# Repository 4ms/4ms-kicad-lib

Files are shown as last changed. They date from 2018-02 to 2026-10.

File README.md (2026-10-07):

4ms-kicad-lib
-------------

Intro:
-----

4ms-kicad-lib is a collection of symbol and footprint libraries for KiCad 10.
These libraries were created by and for people working at [4ms
Company](https://4mscompany.com). We share them publicly in hopes they help
others design great circuits. Have fun.

There are also some legacy symbol libraries for KiCad 5.1.x in
`symbols-legacy`, but they will not be updated or maintained, and they aren't
included in the KiCad Plugin and Content Manager archive.

We tried to follow the KiCad Library Conventions, although we made breaks from
that where it made sense. We also tried to keep the look and feel of the
official KiCad symbols, to make using this library and the official KiCad
libraries seamless.

What's in here:
--------------
__Libraries (KiCad PCM archive):__

`symbols`: The symbol library (schematic symbols). As of May 2020, we have
switched to using a unique symbol for each physical component that might appear
on a BOM line.

`footprints`: The footprint library (pcb). Library names tend to follow the
standard of the official KiCad .pretty libraries, but with a "4ms_" prefix. One
interesting library is the `4ms_Faceplate.pretty`: these are intended to be
used with our faceplate generation scripts. Each component is a hole or slot
that's the correct size for a particular faceplate-mounted component. 

`3dmodels`: 3D models for the footprints, organized similar to how the official
KiCad 3dmodels are organized.

__Other stuff (not in KiCad PCM archive):__

`design-blocks`: These are design blocks that we re-use. We're still new to
this workflow, so it's not part of the PCM release until we figure out how to
best package these.

`symbols-legacy/kicad5-2021`: The legacy symbol library for KiCad 5.1.x. This
is a snapshot of the libraries at Nov 19, 2021. It will not be updated or
maintained.

`symbols-legacy/kicad5-2019`: An even older library using non-atomic symbols
(generic resistor, capacitor, etc). This was deprecated in May 2020. It is no
longer maintained or updated.

`footprints-legacy`: The legacy footprint library, not really of much use since
PCBs embed the footprints they used.

`packages3d`: Legacy random 3d models, please verify dimensions before relying
on the accuracy of these models.

`lib-table-files`: The library table files. People working on 4ms projects
should copy these into a project directory (See step 2B below).

`schematic-blocks`: KiCad schematic sheets of basic circuits we use over and
over. These building blocks are intended to be used as hierarchical sheets, or
just copy/pasted into your design. They are in KiCad 5 format at the moment but
can be used by KiCad 6 as well.

How to Install Symbol and Footprint Libraries:
----------

__Step 1) Download or install the 4ms libraries__

Download or clone the 4ms-kicad-lib git repo onto your local hard drive. Or use
KiCad's Plugin and Content Manager (PCM) to install this.

If downloading manually, save this repo folder in the same directory as all
your KiCad projects or wherever you want to keep you KiCad libraries.

If you use the KiCad PCM tool, the libraries will be installed in your
`KICAD6_3RD_PARTY` directory (on macOS it's
/Users/YourUserName/Documents/KiCad/6.0/3rdparty, for example).

__Step 2) Add the libraries to your library tables__

  * Select `Manage Symbol Libraries` (in the schematic editor) or `Manage
    Footprint Libraries` (in the pcb editor) in the Preferences menu.
  * Select the Global tab (if you want to access these libraries from *all*
    your projects), or select the Project tab (if you just want to use the
    libraries in the current project).
  * Click the tiny folder icon at the base of the list box, and then browse to
    the libraries you want to add. On MacOS you can Cmd-click to select
    multiple libraries at once.
  * Repeat for both the symbol libraries and the footprint libraries.
  * Libraries can be available but just hidden (disabled). To enable/disable a
    library, use the checkbox next to the libraries name.

__Alternative step 2) Setup the environment variables and copy lib tables__

If you want to add **all** the 4ms libraries to your project (which is what
anyone working at 4ms will always want to do), then just copy the two files in
lib-table-files/ to your project directory.

For this to work, you need to first create an environment variable called
`KICAD_4MS_LIBS` and set it to the path to this library folder. You only have
to do this part once, it applies globally to all projects. To do this:
    * Go to the KiCad project window and select `Configure Paths` in the
      `Preferences` menu. 
    * Add a new entry with the name `KICAD_4MS_LIBS`. Set the value to the full
      path of the 4ms-kicad-lib folder. Example: `KICAD_4MS_LIBS:
      /Users/YOURUSERNAME/WhateverFolder/MyKiCadProjects/4ms-kicad-lib`

More resources
----------

The symbol library works well with our BOM scripts (exporting files compatible
with JLCPCB, for example). We also have a series of scripts that generate a
Eurorack faceplate from a PCB, and more. These can be found in our script repo:
https://github.com/4ms/4ms-kicad-script

LICENSE
-------

These are in the public domain under the Unlicense.

TODO
----

  * Add better descriptions for each library

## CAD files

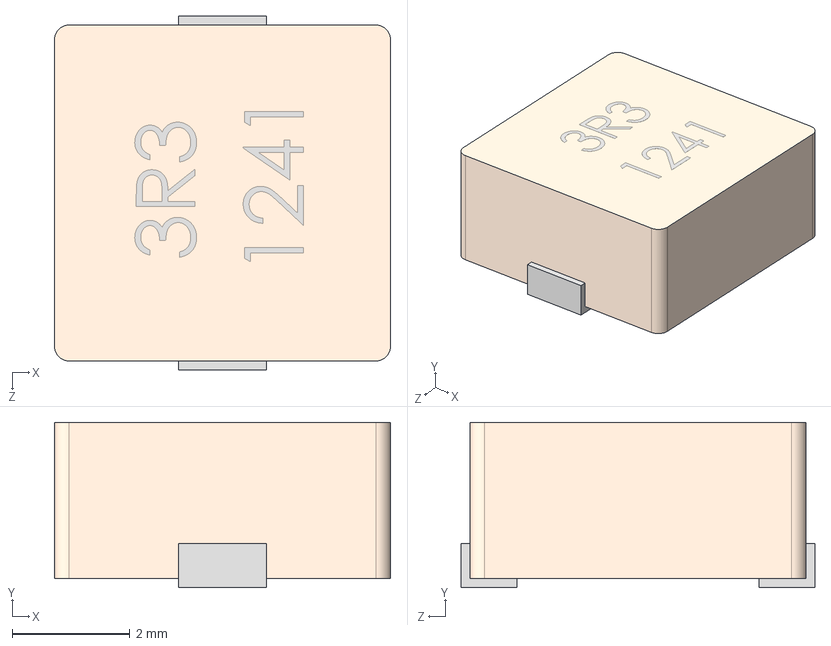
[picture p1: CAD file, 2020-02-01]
3dmodels/Inductors/SRP5030T.step
5.70 x 2.80 x 6.00 mm

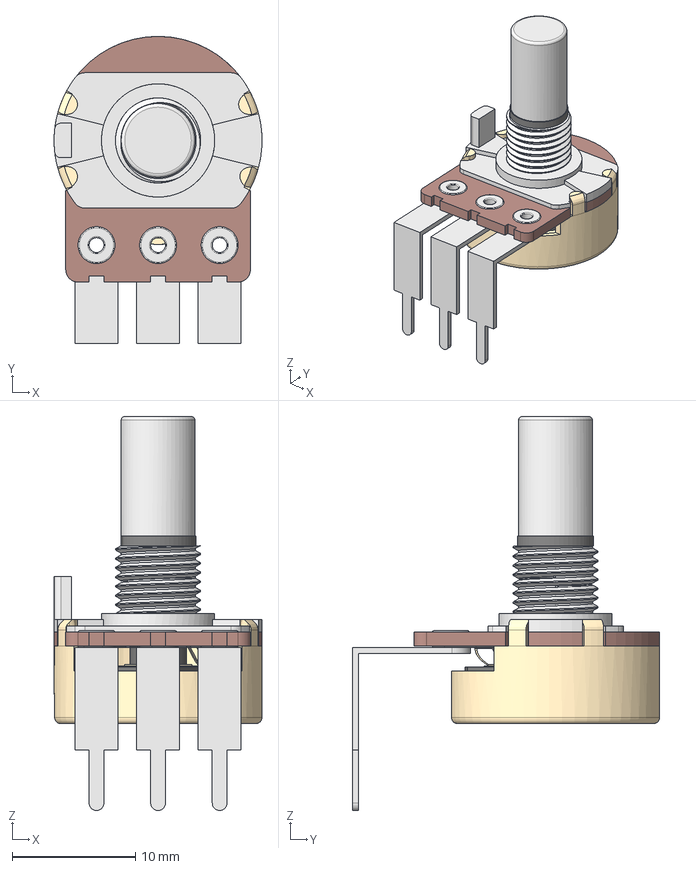
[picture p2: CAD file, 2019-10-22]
3dmodels/potentiometers/16mm Pot Round shaft unknown.step
16.9 x 24.9 x 32.0 mm

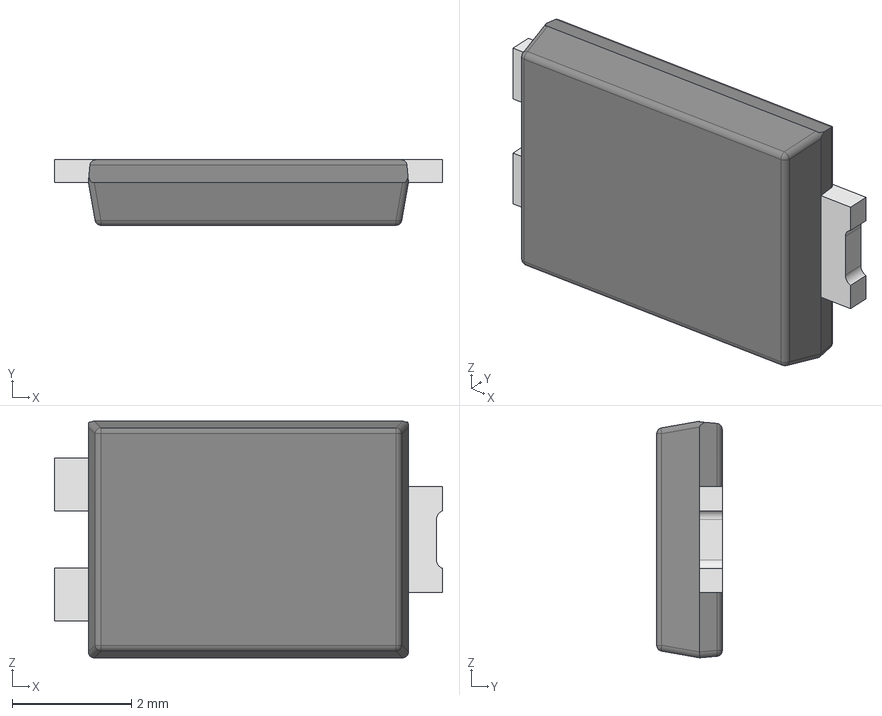
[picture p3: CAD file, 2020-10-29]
3dmodels/PowerDI5.stp
6.51 x 1.10 x 3.97 mm
PD-5 compound
PD-5 LF_0
PD-5 LF

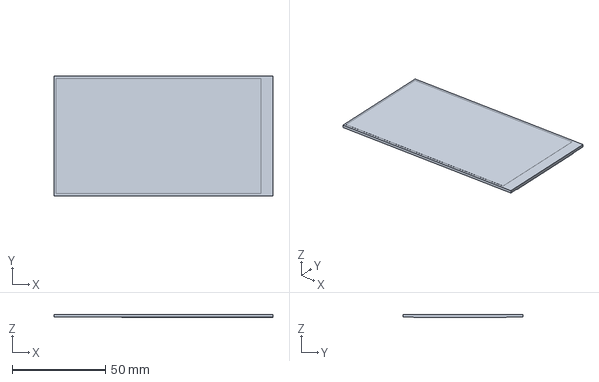
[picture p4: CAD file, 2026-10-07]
src-3dmodel/ER-TFT050-10.FCStd
117.4 x 64.6 x 1.86 mm

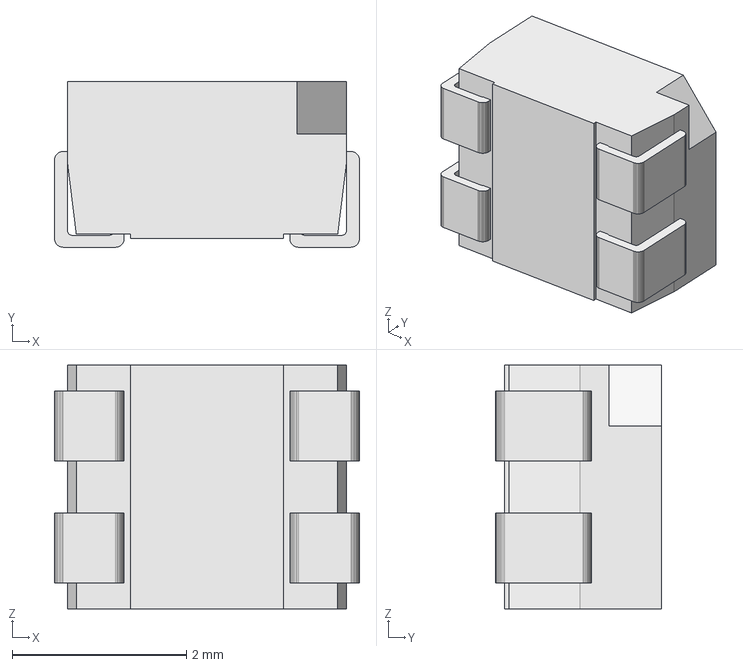
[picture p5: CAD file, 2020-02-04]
3dmodels/PLCC4RGBCT-CA LED SMD RGB2.step
3.50 x 1.90 x 2.80 mm

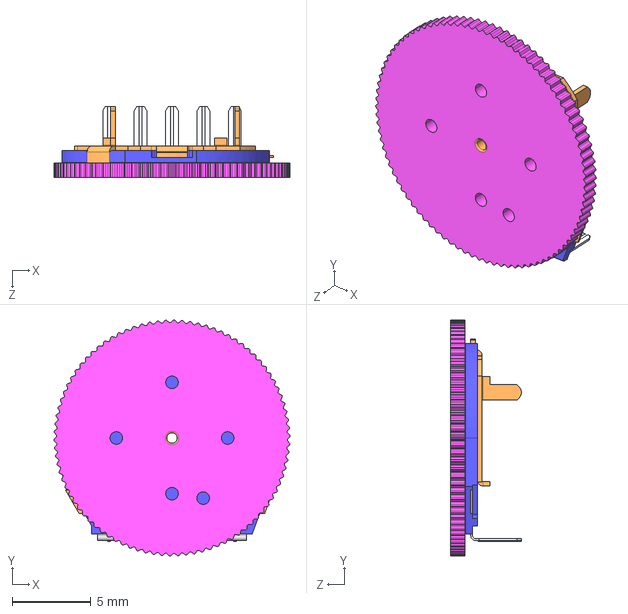
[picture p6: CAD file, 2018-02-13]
3dmodels/potentiometers/RK14J1_A.STEP
15.0 x 15.0 x 4.50 mm

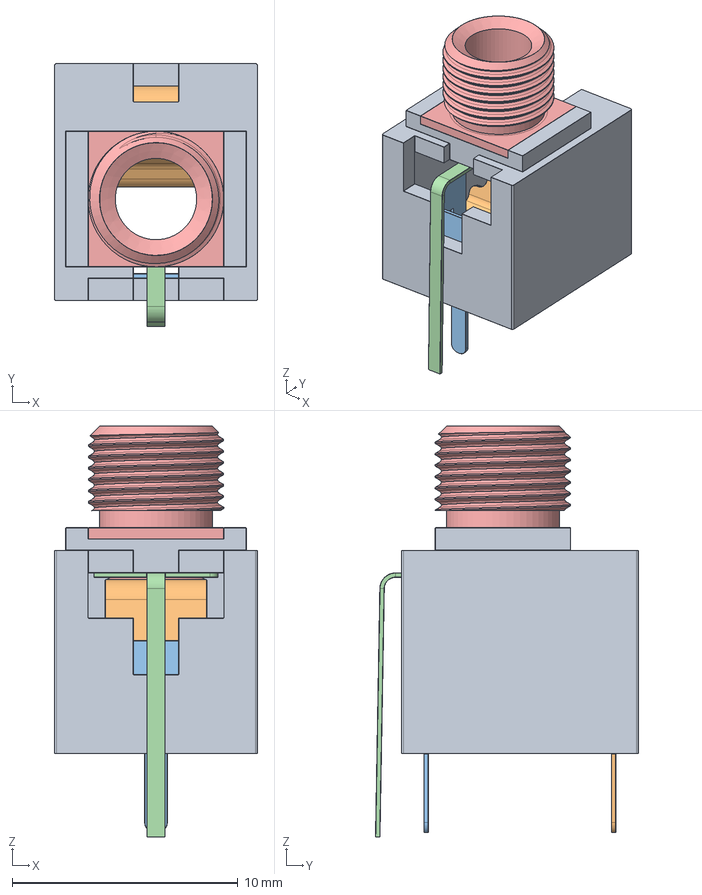
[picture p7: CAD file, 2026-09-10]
src-3dmodel/WQP-PJ398SM.FCStd
9.00 x 11.6 x 18.2 mm
Pin 3
Pin 2
Pin 1
Socket

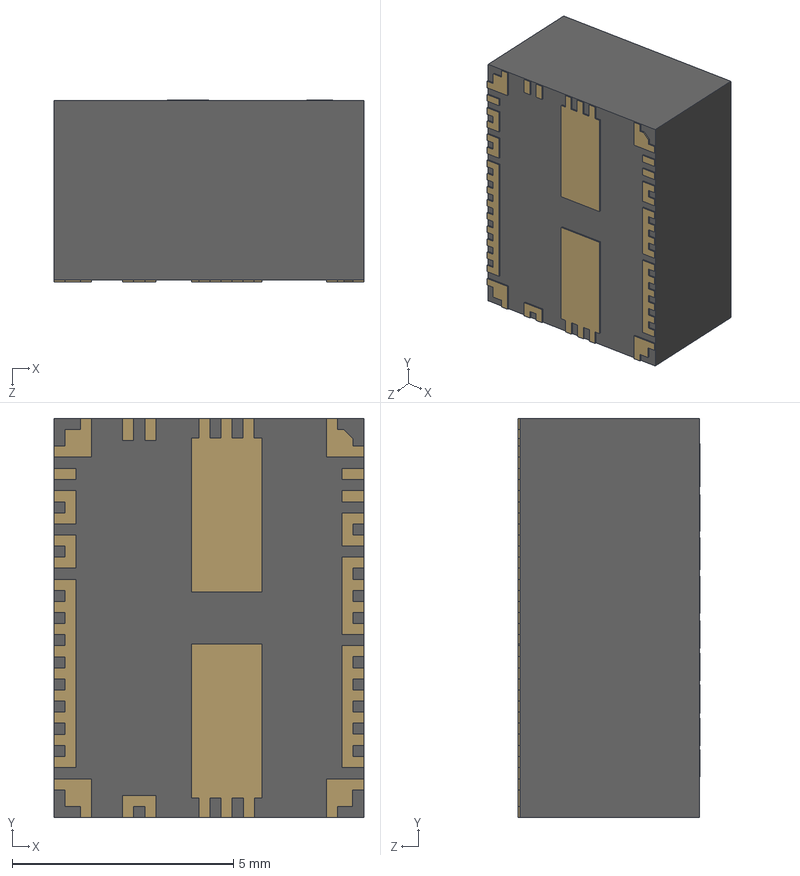
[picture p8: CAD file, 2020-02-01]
3dmodels/LMZM33602.STEP
7.00 x 9.01 x 4.11 mm
ShapeString

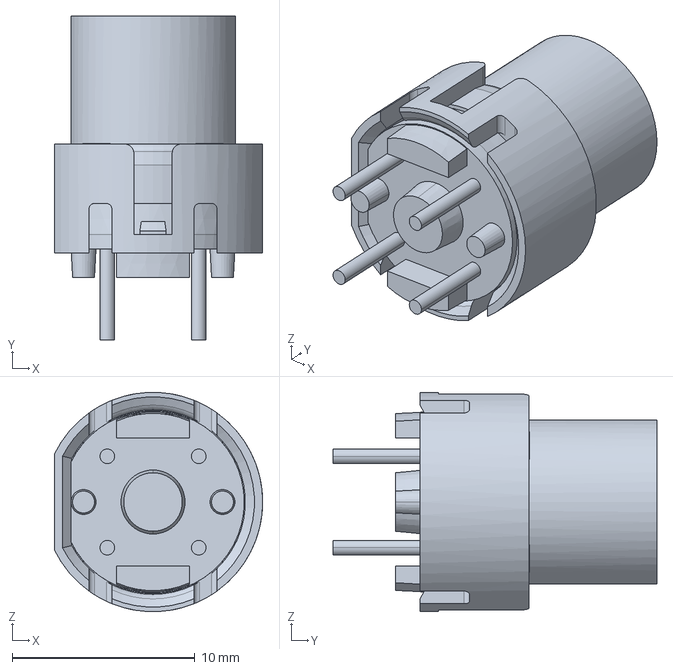
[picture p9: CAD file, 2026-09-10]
src-3dmodel/CK_DCR.FCStd
11.4 x 17.7 x 12.0 mm

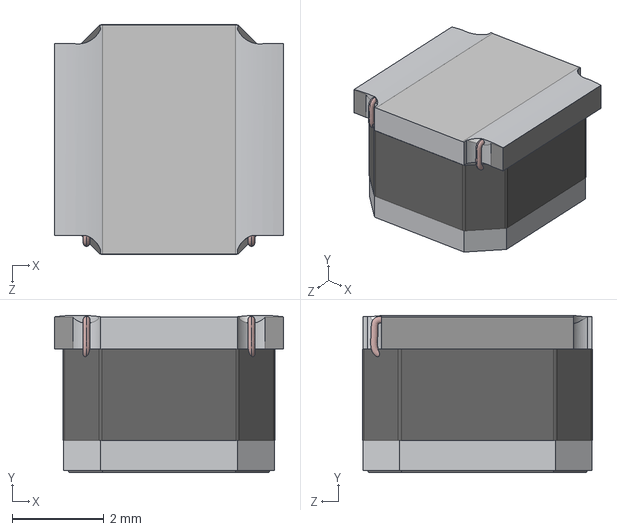
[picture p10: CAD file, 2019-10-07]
3dmodels/SRN5040.stp
5.00 x 3.44 x 5.02 mm

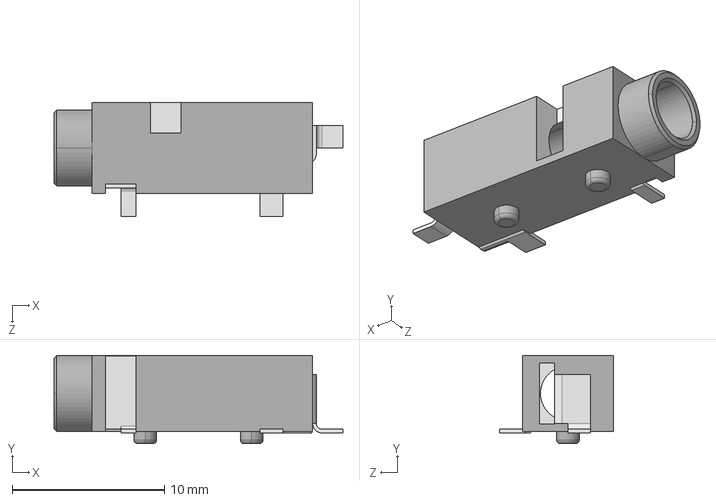
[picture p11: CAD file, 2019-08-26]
3dmodels/CUI_MJ-3523-SMT.step
19.0 x 5.80 x 7.50 mm

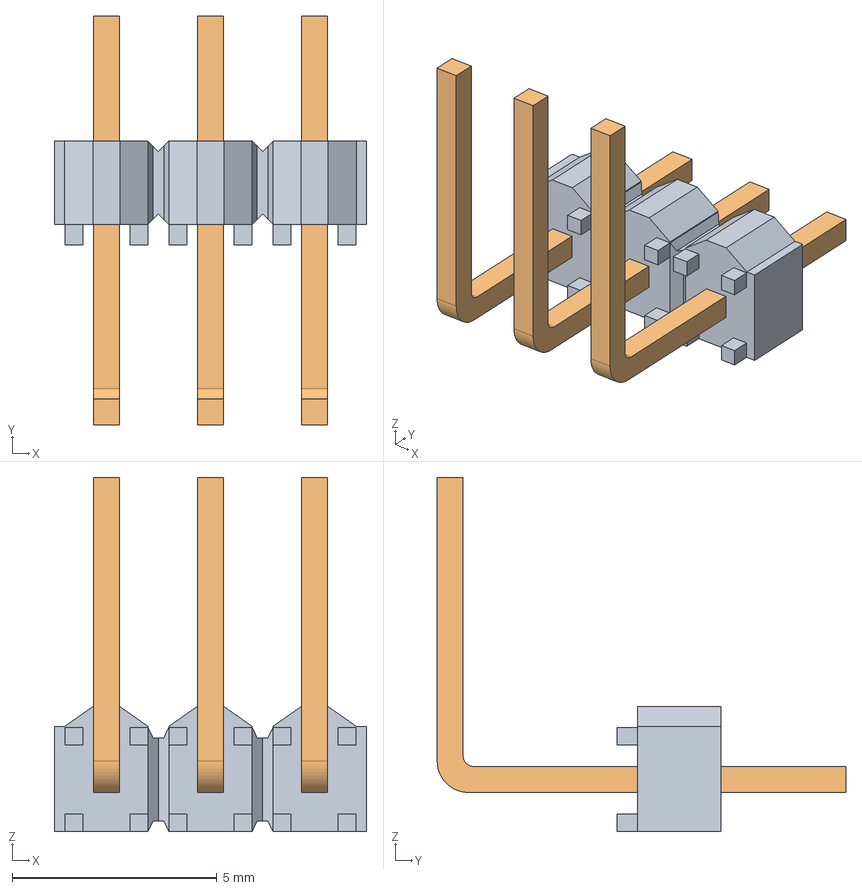
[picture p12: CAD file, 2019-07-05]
3dmodels/HMTSW-103-22-T-S-120-RE.stp
7.62 x 9.97 x 8.64 mm
_HMTSW-103-22-T-S-120-RE_body
_HMTSW-103-22-S-120-RE

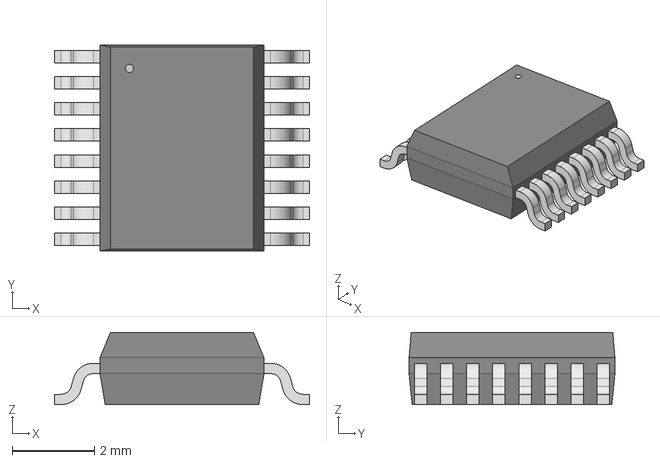
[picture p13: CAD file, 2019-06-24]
3dmodels/DBQ16.step
6.20 x 5.00 x 1.75 mm

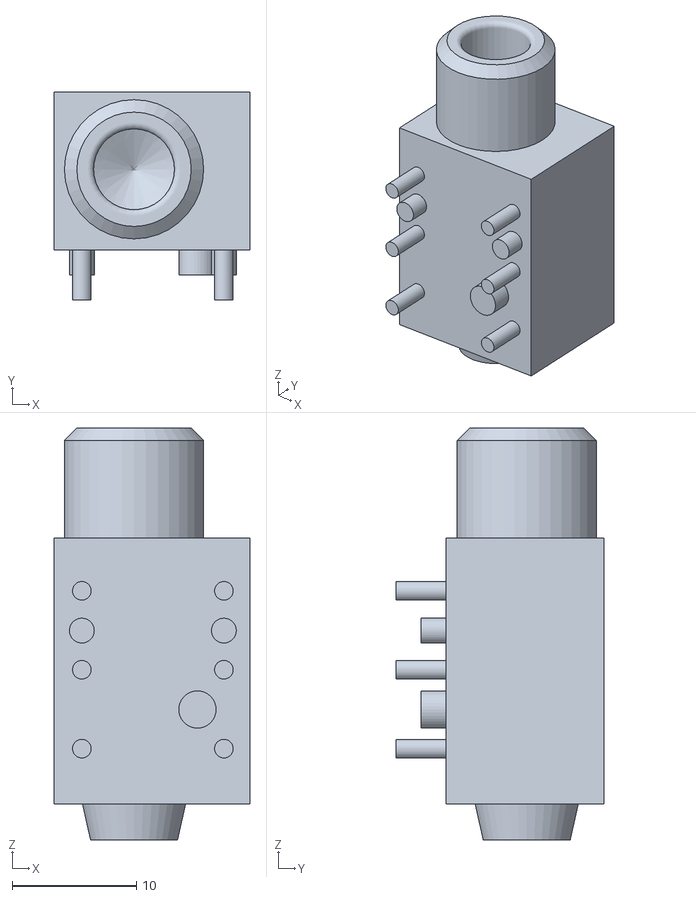
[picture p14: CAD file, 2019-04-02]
3dmodels/jack_NRJ6HF.stl
15.7 x 16.7 x 33.1

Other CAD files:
3dmodels/c-2267077-2-a-3d.step
3dmodels/TSS-108-01-G-D.stp
3dmodels/neutrik-NRJ6HF.stl
3dmodels/CUI_PJ-064A.STL
3dmodels/CUI_PJ-064A.obj
3dmodels/CUI_PJ-066A.STL
3dmodels/PLCC4RGBCT-CA LED SMD RGB2.stl
3dmodels/c-2267077-2-a-3d.igs

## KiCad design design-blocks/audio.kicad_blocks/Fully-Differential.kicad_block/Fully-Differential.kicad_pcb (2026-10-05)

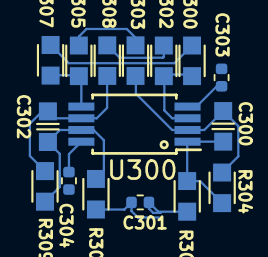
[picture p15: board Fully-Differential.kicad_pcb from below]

Board: 2 copper layers, 16 parts (16 on the bottom side), 14 nets.

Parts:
C300, C302: 100pF_0603_50V; C_0603
C301: 10nF_0402_16V; C_0402
C303, C304: 100nF_0402_16V; C_0402
R300, R303, R305, R308: 100k_0603_0.1%; R_0603
R301, R306: 47Ω_0603; R_0603
R302, R304, R307, R309: 14k_0603_0.1%; R_0603
U300: TL072H; TSSOP-8_4.4x3mm_Pitch0.65mm

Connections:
+12V_B: C304.1, U300.8 (V+)
-12VA_B: C303.1, U300.4 (V-)
/Audio/In1_A+: R300.1, R308.1
/Audio/In1_A-: R303.1, R305.1
/Audio/VCOMAD: R302.2, R307.2
/Audio/VIN4+: C301.1, R301.2
/Audio/VIN4-: C301.2, R306.2
GNDA: C303.2, C304.2
unnamed: C300.2, R301.1, R304.2, U300.1
unnamed: C302.2, R306.1, R309.2, U300.7
unnamed: R300.2, R302.1, U300.3 (+)
unnamed: C300.1, R303.2, R304.1, U300.2 (-)
unnamed: R305.2, R307.1, U300.5 (+)
unnamed: C302.1, R308.2, R309.1, U300.6 (-)

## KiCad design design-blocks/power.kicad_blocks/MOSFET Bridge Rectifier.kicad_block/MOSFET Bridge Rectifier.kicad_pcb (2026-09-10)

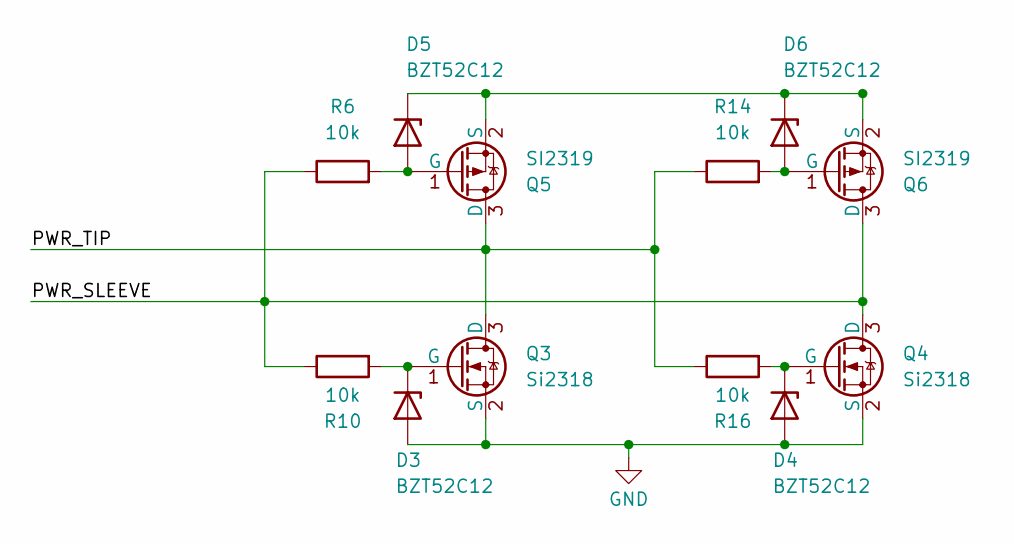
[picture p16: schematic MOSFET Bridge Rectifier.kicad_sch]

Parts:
D3, D4, D5, D6: BZT52C12; D_SOD-123F; Part Number BZT52C12; JLCPCB ID C19077447
Q3, Q4: Si2318; SOT23-3_PO132; Part Number SI2318DS-T1-GE3; JLCPCB ID C14498
Q5, Q6: SI2319; SOT23-3_PO132; Part Number SI2319DDS-T1-GE3; JLCPCB ID C3290067
R6, R10, R14, R16: 10k_0402; R_0402; Part Number 0402WGF1002TCE; JLCPCB ID C25744

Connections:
/PWR_SLEEVE: Q4.3 (D), Q6.3 (D), R6.1, R10.1
/PWR_TIP: Q3.3 (D), Q5.3 (D), R14.1, R16.1
GND: D3.2 (A), D4.2 (A), Q3.2 (S), Q4.2 (S)
unnamed: D3.1 (K), Q3.1 (G), R10.2
unnamed: D4.1 (K), Q4.1 (G), R16.2
unnamed: D5.2 (A), Q5.1 (G), R6.2
unnamed: D5.1 (K), D6.1 (K), Q5.2 (S), Q6.2 (S)
unnamed: D6.2 (A), Q6.1 (G), R14.2

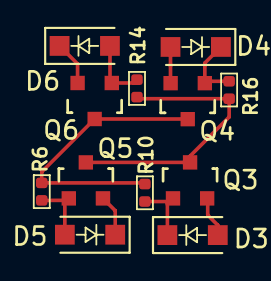
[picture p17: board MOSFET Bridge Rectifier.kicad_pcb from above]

Board: 2 copper layers, 12 parts (0 on the bottom side), 8 nets.

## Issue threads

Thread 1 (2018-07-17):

Invalid KiCad footprints

ext-marko-marjanovic, 2018-07-17:
I tried to import KiCad footprints (directly, bypassing your installation manual) and found that the following three were marked as invalid by KiCad:
- Pin_Header_Straight_1x03.kicad_mod
- Slide_Switch_SPDT_Nexsun_MS2201L6.kicad_mod
- Slide_Switch_SS22D06-G6-H_Runrun.kicad_mod

Using KiCad 4.0.7 on Win10

danngreen, 2019-02-11:
Sorry, I didn’t note in the docs that the footprints and symbols require Kicad 5 or newer.
I believe what those three footprints have in common are custom pad shapes, which Kicad 4 does not support.

Closed 2021-11-22.

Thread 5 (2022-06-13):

Document Library Convention

danngreen, 2022-06-13:
We follow Kicad Library Convention, but there are some breaks from this.
These need to be documented.

As mentioned in PR #4 header footprints are the origin/anchor at the geometric center of the pins (KLC dictates the anchor is at pin 1)

There are probably other things as well...

danngreen, 2022-06-13:
Also, any panel-mounted component footprint (jacks, potentiometers, LEDs, switches, etc) has the anchor/origin set to the center of the panel hole. This allows us to use scripts to create a faceplate from a PCB without needing to maintain a database of XY offsets for each component. It also makes it easy to rotate panel components without changing the faceplate layout.

danngreen, 2022-06-13:
Custom fields in symbols:
`Specifications` should have enough information for an assembly house to uniquely identify a part (Min/max values, tolerance,...)

`Part Number`
`Manufacturer`

then optionally:
`Part Number 2`
`Manufacturer 2`
`Part Number 3`
`Manufacturer 3`
...etc...

All Part Number/Manufacturer pairs should be equivalent and substitutable for each other.

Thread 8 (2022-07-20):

Better Audio Jack symbol

electron271, 2022-07-20:
I feel that the current audio jack symbol is a bit too big/complex, I would make it smaller in favor for something else (I think the default KiCAD one is good)

electron271, 2022-07-20:
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
I sketched up this crude design, might work

Closed 2024-01-30.

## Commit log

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2017-09-20 changed logo footprint to say '4ms Company' in schematic view. said 'ttplace' before..
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2017-10-12 Fixed mask on faceplate footprint M-12 Jack
    (was silk over the hole, but no mask. Removed the silk and added the mask)
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2017-11-01 PCB: Added dual 3-lead LED with Med/Long/Short note for lead length
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2017-11-28 Pin Header 1x6 footprint: Removed silkscreen over pads
    Moved value field from F.Fab to F.Silk
2017-11-28 EuroHeader footprint: centered over
    I checked to make sure no designes are using this piece before commiting: Only RECORDER-p2.1 (design has been updated).
2017-12-06 4ms Footprint library overhaul begun (WIP)
    lib-footprints folder added with copies of all 4ms-footprints.pretty/ modules. Todo: rename and cleanup all footprints.
    Also added fp-lib-tables for global config using just 4ms footprints, and a project level fp-lib-table for using kicad libs
2017-12-06 adjusted CP_Tantalum silkscreen to indicate polarity more clearly
    created reverse side 2x4 header for the L4Q project and included in 4ms-footprints library
    Created NP cap footprint in 4ms-footprints library
2017-12-07 updated V2164 IC so that the power pins only appear on unit A
2017-12-07 footprint lib: Added 3-lead LED wiht MLS marking
    Medium, Long, Short leads
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2017-12-13 Footprints: updated courtyards of LDR and 7805
    Had excess lines in courtyard which flagged a DRC error
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2017-12-22 Updated Diodes to KLC standards - please see TODOIST for comments
    Unclear about the two SOT-23 version we have
2017-12-29 Added 4ms_Faceplate footprints and added mask openings
    -FaceplateHole_EncoderRGB_NoBushing
    -Lightpipe_WithMaskOpening
    Added mask opening to LEDButton_305 and RGBLEDButton
2018-01-02 Footprints: diodes: renamed SOT-23 "Swap" and "RotatedCW"
    New names refer to the PinOrder
    SwappedPins => PinOrder123
    RotatedCW => PinOrder213
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2018-02-09 symbols: added some common parts
    1x headers
    MCP1703x
    renamed LED(?)
    added capacitors
    added power symbols
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2018-02-13 lib-footprints: fixed bugs in 4ms_Connector
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2018-02-14 lib-footprints: 4ms_Jacks fixed swapped pins on rt angle jack
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2018-02-15 lib-footprints: Updated - 4ms-LED - fixed mistake
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2018-02-15 lib-footprints: Fixes
    backwards DP3T switch, thumb wheel pot courtyard was not a polygon, wrong 3D file linked to PJ301M-12 jack, removed wrong 3D for VXO78xx
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2018-02-15 updated switch and SOIC footprints to kicad standards. removed ATTINY from DIP folder
2018-02-15 updated testpoint footprints to kicad standards. refined switch footprints, renamed SOIC footprint
2018-02-16 reduced courtyard to .25mm for R0603 & D_SOD-123, reduced pad clearance to eliminate DRC errors on SSOP, updated silkscreen on Tantalum cap
2018-02-16 lib-footprints: Fixed courtyards in 4ms_Connectors
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2018-02-16 lib-footprints: bug in 4ms_Jacks courtyard
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2018-02-16 lib-footprints: fixed encoders crt'yrd issue
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2018-02-16 lib-footprints: fixed LED right angle crt'yrd
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2018-02-20 lib-footprints: Fixed SSOP-28 package
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2018-02-20 lib-sch: Split SPST-ILLUM-RGB into two symbols
    One for 5.4mm Well Buying pin ordering, one for 7mm RunRun pin ordering. The B and G are swapped if you compare the two buttons.
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2018-03-05 lib-fp: 4ms Connectors: Added 1x4 MTA156 connectors
    Whitespace change to 1x3 audio headers
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2018-03-08 lip-fp:4ms Connectors: fixed font size on 2x3 and 2x8 header and socket
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2018-04-09 fp: fixed right angle switch
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2018-04-09 fp: added barrel jack right angle, 1/4" jack rt angle with switches
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2018-04-09 Fixed V2164-separate-power
2018-04-12 fp: Added RGB SPDT SMD button for the RGB Adapter on the SWN p2.3F7
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2018-05-13 fp + 3D: Added dual pots (RV112 and RK09)
    [RK12L1230C0K.STEP]
2018-05-13 sch: fixed extra power pins on V2164-separate-power
2018-05-29 sch: added RBG LED to library from SMR import- still needs to be renamed
2018-05-29 Fixed 3D paths and added a couple 3D models
2018-05-29 Fixed unnumbered pins 7,8 on ALPS 9mm dual pot
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2018-06-12 fp: fixed encoders - nc legs were too wide for the encoders to sit flat
2018-06-12 fp: labelled new encoders with 'nudged' at the end - verifying fp
2018-06-18 Added 3D models for Yamaichi PJS microSD card connector, and Recom 78E
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2018-07-12 fp: added and fixed 3D models for many devices. Added adhesive mount post
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2018-07-20 Add Knurled 11mm dual pot and fix orientation of 9mm dual metal shaft
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2018-12-07 Added ALT-GND eight inch jacks for passive mult
    Panel script needs to be updated with this part
2018-12-07 Fixed 3D file for 6mm trimpot
2018-12-07 New FP hole: RGB Encoder with hole big enough to fit knob
    (so faceplate can be removed without removing knob)
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2019-01-21 Created eurorack header footprint with less silk (for fitting in smaller places)
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2019-01-21 3D: SPDT sub-mini flip switch model
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2019-02-06 Added schematic blocks: gate input and bipolar cv input
    [bipolar_cv_input.sch, gate_input.sch]
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2019-05-27 Fixed XLR footprint - added a temp one for prototyping
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2019-06-09 Added schematic block for dcdc converter for 3.3V power
    [uc_power.sch]
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2019-07-12 Re-added Stereo Jack with 2 Switches, and fixed footprint pins to match
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2019-08-02 sch-blocks: added 5V power supply
    [uc_power_5V.sch]
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2019-08-05 fp: fixed link to 3d model for some connectors
2019-08-07 schematic blocks: added WM8731 codec
    [audio-codec-WM8731.sch]
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2019-09-04 fp: fixed 3d link for 2x10 SMT 1.27mm header
2019-09-04 fp: fixed 3D link for all Pin headers in 4ms_Connectors
2019-09-16 fpEncoders-replaced encoders with NUDGED versions - renamed w/ OLD
    started using better footprints for encoders - support legs are nudged inwards to keep them in place
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2019-09-18 added 9v regulator and fixed 9v power pin
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2019-10-22 3d and fp: Created Alpha 16mm Pot D-shaft model and attached it to fp
    [AlphaTaiwan-RV16AF-4A-15FW.FCStd]
2019-10-23 sym: fixed wrong pin# in STM32G070
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2019-11-09 DCDC converter 3d model and symbols
    [audio-codec-cs4271.sch]
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2019-11-12 sym: Added rescue parts from DLD
    [uc_power.sch]
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2020-02-04 3d:RGB LED step model for kicadStepUp
    [PLCC4RGBCT_CA_LED.FCStd]
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2020-05-22 Updated README, cleaned up unused stuff.
    Renamed directories to make more sense.
    Removed dual lib tables, and now just have one 4ms-only library table file to be added to all projects
    [audio-codec-WM8731.sch, audio-codec-cs4271.sch, bipolar_cv_input.sch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]
2020-05-22 Added new symbol library, avoiding the use of generics.
    All symbols contain full BOM information. Most symbols are fully-specified (See KLC G2.1).
    Resistors, Caps, Inductors are no longer generic.
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2020-08-19 lib-sym:Switch fixed 12mm encoder name to 11mm
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2020-08-24 Fixed Net Tie (had two pin 1's)
2020-08-24 Fixed GND2 (was on GND net)
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2020-09-09 sym: Added JLCPCB ID for several components
    Fixed 49.9R resistor displaying 1.1k
    Fixed (added) 40.2k resistor (was a dupe of 40.4k)
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2020-09-09 sym: IS25L flash RAM V+/GND pins had wrong types
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2020-10-29 JLCPCB: Started on Resistor lib - added ToDo.txt to keep track of status and make notes
    [Resistor.csv]
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2020-10-29 JLCPCB: FInished resistors.lib and updated ToDo.txt
    [Resistor.csv]
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2020-10-29 JLCPCB: Added IDs to Capacitors.lib
    [Capacitor.csv]
2020-10-30 JLCPCB: Added one or two IDs to Diode.lib
    [Diode.csv]
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2020-12-16 SYM: TMUX-Fixed duplicant pin, MAX-Made datasheet invisible
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2020-12-17 SYM: Updated Connector 0x09 with correct fields and footprint FP: Added Pins_1x09 to lib
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2020-12-22 Added schematic block for jacksense with mono jack
    [jacksense_input_monojack.sch]
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2020-12-22 Fixed pin types for net tie and MAX11666
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2020-12-31 Removed clearance guide circle on several faceplate footprints
    Eco1.User layer
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2021-01-26 FP: Fixed 10-Pin RUG package - pin order was back mirrored
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2021-06-23 SYM: Fixed UA78L09 pin orientation to match footprint and datasheet
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2021-08-09 sym: fixed name of small stereo jack (it's not switched), and changed pin XY
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2021-08-16 Fixed Net Tie (needs "net tie" at start of tags, case-sensitive)
2021-08-16 Fixed Rail Connection 12HP (was kicad v6, re-did it as kicad v5)
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2021-08-31 sym: added 10k 0402, fixed 47Ω "Part Number 2" field name
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2021-11-20 Converting to KiCad Addon format
    eagle libraries removed
    gerbv_templates moved to 4ms-kicad-scripts repo
    [16mm Pot Round shaft unknown.step, AlphaTaiwan-RV16AF-4A-15FW.FCStd, AlphaTaiwan-RV16AF-4A-15FW.step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]
2021-11-20 Re-arranged directories again, for ease of use with KiCad PCM
    [audio-codec-WM8731.sch, audio-codec-cs4271.sch, bipolar_cv_input.sch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]
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2021-11-22 Fixed sym-lib-table to indicate `KiCad` format
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2021-11-23 fp: microSD card slot (Yamaichi vertical), fixed capitalization of tags
2021-11-23 fp: R_0603: fixed silk overlap with soldermask error
2021-11-24 sym: Added tact switch with pins 1+3 shorted, pins 2+4 shorted
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2021-12-22 SYM: Added invisible NC leg to slider symbol to prevent NC DRC errors
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2022-01-12 schematic blocks: added 3.3V DCDC blocks using old ap65211 and new AP62200
    [uc_power_3v3.kicad_sch, uc_power_3v3_ap65211.kicad_sch]
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2022-01-22 Updating the 0402 specs for JLCPCB
    a note* I deleted 175R_0402 resistor because I believe it's in there by mistake. None of the info in there was correct and I can't find the part anywhere in the 0402 size.
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2022-02-03 SYM: Renamed 130k 0603 resistor - there was a mistake
2022-02-08 Fixed pin numbering of TFBGA-257
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2022-02-08 sym: Corrected P/N and datasheet for Socket_02x03_P1.27mm_SMT
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2022-02-18 sym+fp: Trying to fix Net Ties. Kicad is quirky...
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2022-02-18 fp (3d): Fixed all 3d model paths to use Kicad6 env var
2022-02-18 sym: Fixed many resistors footprints to use 4ms fp, hide JLCPCB ID
    Added several 0402 packages
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2022-03-11 SYM: Fixed mistakes on some 0402 capacitors
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2022-05-20 fp: rail connections 26HP (fixed) and 28HP (new)
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2022-05-20 sym: fix pin types of LD1117
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2022-05-31 fp: fix SOT223 tab being different pin number than center pin
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2022-05-31 sym: Fixed wrong resistor part numbers
2022-06-01 Added 0603 1% resistor library with verified JLCPCB IDs
    Missing ones are:
    2.16
    11.2
    11.7
    14.2
    19
    21.6
    22.5
    26
    33.1
    35.6
    40.1
    41.2
    57.5
    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
2022-06-06 Fixed JLC numbers for a few resistors
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2022-06-10 Generated resistor libraries for 0402, 0603, 0805 | 1%, 0.1%
    Checked JLCPCB IDs. Errata:
    0402-0.1pct
    R234 2.74M: package is 2512 instead of 0402
    R42 27.4K: package is 0805 instead of 0402
    R189 931K: package is 2010 instead of 0402
    0402-1pct-1-9.76k
    R304. 1.47k: 0.1% instead of 1%
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2022-06-13 Revert "Update 4ms_Jack.kicad_sym"
    This reverts commit 483a6172d84802f4796af18b07969697f299712a.
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2022-07-26 sym: Fixed 9mm 100k no det knurled P/N. Cleanup other P/Ns
2022-08-10 sym: Fixed wrong value in 17.4k resistor specs (said 17.5k)
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2022-08-19 sym: fixed missing N/C pin on SDRAM
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2022-08-22 Fixed rounding errors in resistor generator's values
    e.g. 40.1k was added not 40.2k, but the latter is E96
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2022-08-26 Made an error when creating the VREF- that caused it to combine with -12v - fixed now
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2022-09-11 fp: Fixed silk on 16mm pots, 9mm pots, and stereo jack to not overlap
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2022-10-08 sym: Fix BGA SDRAM footprint (link to BGA), and add NC pin
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2022-10-27 fixed 2x5 socket footprint
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2022-12-08 fix typo in spacer footprint
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2022-12-21 fp: Wurth Spacers: fix 3D model orientation relative to footprint
2022-12-21 sym: TH 3mm LEDs: Add blue, white, and fix red manuf/PartNum
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2022-12-21 fp: Fix attribute set to TH, not SMD for various footprints
2022-12-21 sym: Fixed PCA9685 footprint link
2023-01-05 sym: RGB Button 5.4mm: fixed labelling of G/B pins (swapped)
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2023-01-09 sym: fix wrong footprint for 5.4mm cap RGB button (TC002)
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2023-01-15 fp: Fix reversed shroud key on Eurorack power headers.
    General cleanup of 10 and 16 pin eurorack power headers:
    -Removed confusing pin 1 arrow
    -fixed shroud/key orientation
    -added POWER in consistent font and position
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2023-01-27 Revert "fp: Fix reversed shroud key on Eurorack power headers."
    This reverts commit 998adc6cb4a616bc7ab18ed870c169bfb0729500.
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2023-01-29 Revert "SYM: Added DNP P and OR resistor symbols to Resistors_0402 and Resistors_0603"
    This reverts commit da5e4de3a7a485cbf66486f5091d5cef4c728511.
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2023-02-21 sym: fix PCM3168 pin types
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2023-03-27 Added missing Production Stage (lost in K7 update)
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2023-03-27 sym: Added Production Stage to several inductors that were missed
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2023-04-06 sym: Fix pin positions of AZ1117CR-3.3
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2023-04-19 sym: fixed pinout of PB20B button (swapped pins 2+3)
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2023-04-26 SYM: 12mm hollow encoder Unit B was not on correct grid. Fixed unit B
2023-04-26 SYM: 12mm hollow encoder Unit B was still off grid - fixed and verified
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2023-05-02 SYM: Fixed 3.3VREF and 3.3VLED power syms - pins were still labelled 3.3V
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2023-05-03 SYM: Fixed shield pins on hollow encoder - shield pins were not labelled correctly
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2023-05-04 SYM: Symbol had old pin labelling and was not updating to footprint correctly
2023-05-04 FP: Labelled pins on 60mm slider to avoid 'no net' errors
2023-05-16 FP: fix silkscreen overlapping solder mask (DRC warning) in PB615303HL RGB button
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2023-06-23 FP: Removed cicle and cross silk screen on hollow encoder to prevent DRC errors with LED silk
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2023-07-27 sym+fp: Add correct footprint for Top-Up slider 60RFT
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2023-12-05 FP: reduce DRC errors in 1x2 tiny bridged solder jumper
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2023-12-11 SYM: Added production stage: D to any assembly library parts missing this field
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2023-12-18 sym: switch: Fix PKS-01L part number:
    was PKS-001L-5C, should be PKS-01L-5C
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2025-01-14 fixed pin 1 on 7660S
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2025-01-22 fixed solder mask
2025-01-27 Replaced 330nF 25v - old part had conductive epoxy termination
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2025-05-05 Added 3.55mm horizontal stereo switching jack sym-fp-3d, fixed an battery related IC a regulator
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2025-06-04 fp/3d: add models for connectors from last commit
    [TSW-102-08-T-S-RA.stp]
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2025-07-03 sym: Fix use of local fp in 2x40 connectors
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2025-10-08 sym: fix "3.5mm Stereo Switched Jack" misleading artwork
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2025-10-08 SYM/FP: Updated EN12-HS22AF18 with correct pin numbering
2025-10-13 IC sym: fix some pin types and 0-height fonts
2025-10-13 sym: Fix trailing spaces and typos in IC and Regulator libs
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2025-12-01 sym: LP5009: fix pin types
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2025-12-13 Fixed 3D placement for tact switch
2025-12-13 FP: Added faceplate hole for 5mm tact twitch
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2025-12-14 FP: Added correct pin numbers for Tact swithc
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2025-12-20 sym/fp: fix pin number mismatch for motorized pot
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2026-01-02 sym: fix DRV8210 pin type
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2026-03-05 FP: Resolved silkscreen overlap DRC warnings for components
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2026-03-11 sym: fix part number of TL1105 round black button
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2026-03-12 SYM: Updated fields for STM32MP135DAF7 to be output correct information in BOM generation
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2026-04-28 Add SSW-104 socket symbol, fix pin header 3D model path
    - Add Socket_1x04_P2.54mm_Horizontal_TH_Samtec_SSW104 symbol with footprint pre-linked
    - Pins_1x04_P2.54mm_Horizontal_TH: update 3D model to STEP via KICAD_4MS_LIBS
    - Add PinHeader_1x04_P2.54mm_Horizontal.step from KiCad built-in library
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2026-05-18 Add Faceplate_Hole_Switch_MX footprint, add STP model to Cherry MX WithDSACap
    - Faceplate_Hole_Switch_MX: 20.2x20.2mm Edge.Cuts square cutout for Cherry MX keycap (18.2mm base + 1mm clearance each side)
    - SW_Cherry_MX_PCB_WithDSACap: add SW_Cherry_MX_PCB.stp model reference alongside existing WRL so switch body appears in kicad-cli STEP export
2026-05-30 Add Socket_1x04_P2.54mm_Horizontal_TH_Samtec_SSW104_CNTERED footprint
    Right-angle 1x4 socket, footprint center between pins 2-3 (matching
    Pins_1x04 male header center), 3D model offset corrected to match.
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2026-06-03 Rewrite WA-SNTI 15mm footprint in KiCad 10 format, single model entry
    Removes duplicate ${KIPRJMOD} model path that prevented editing in
    footprint editor; keeps only ${KICAD_4MS_LIBS} path.
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2026-08-27 Fix name of mp257 socket C
2026-08-27 sym: add AP3012, AP63300/1, ESP32-C6-WROOM, LP5018
    Fix pin names for mp257 socket
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2026-09-10 block: Add MOSFET Bridge Rectifier design block
    [MOSFET Bridge Rectifier.kicad_pcb, MOSFET Bridge Rectifier.kicad_sch]
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2026-09-10 3d: add model for PB20B button (aka CK DCR)
    [CK_DCR.FCStd]
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2026-09-18 sym: add missing shield pin on double-stacked 1/4" jack
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2026-10-05 fp: Fix path to 2x8 2.54mm vert pin header 3d model
2026-10-05 Add Fully Differential design block
    [Fully-Differential.kicad_pcb, Fully-Differential.kicad_sch]
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2026-10-07 Move 3d models used by footprints from packages3d/ to 3dmodels/.
    Also add missing models that were found in other git branches and
    stashes
2026-10-07 Update/fix all footprint links to 3dmodels
    All links should now resolve to an actual model
2026-10-07 Create design-blocks/ dir, move actual design blocks from legacy schematic-blocks/
    [Fully-Differential.kicad_pcb, Fully-Differential.kicad_sch, MOSFET Bridge Rectifier.kicad_pcb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]
2026-10-07 Move 3d model FreeCAD files to 3dmodel-sources
    [CK_DCR.FCStd, ER-TFT050-10.FCStd, WQP-PJ398SM.FCStd]
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2026-10-07 Fix all 3d model paths: KICAD6=>10, .wrl=>.step
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2026-10-08 sym: Fix wrong footprints
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2026-10-08 sym: Fix footprint link
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2026-10-12 fp: RGB 9mm button: fix silk overlapping soldermask
2026-10-12 fp: 1/4" dual stacked: fix silk overlapping pads, make all pads round rects for traces to fit between
2026-10-12 sym: Fix and remove footprint filters
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2026-10-19 sym: fix JLC numbers, remove fp filters
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2026-11-11 sym: fix Red/Blue LED pins not aligned to grid
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
